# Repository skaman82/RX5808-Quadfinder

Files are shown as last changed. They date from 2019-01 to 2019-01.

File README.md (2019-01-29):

# RX5808-Quadfinder
Modified RX5808 Pro firmware for my Quadfinder project

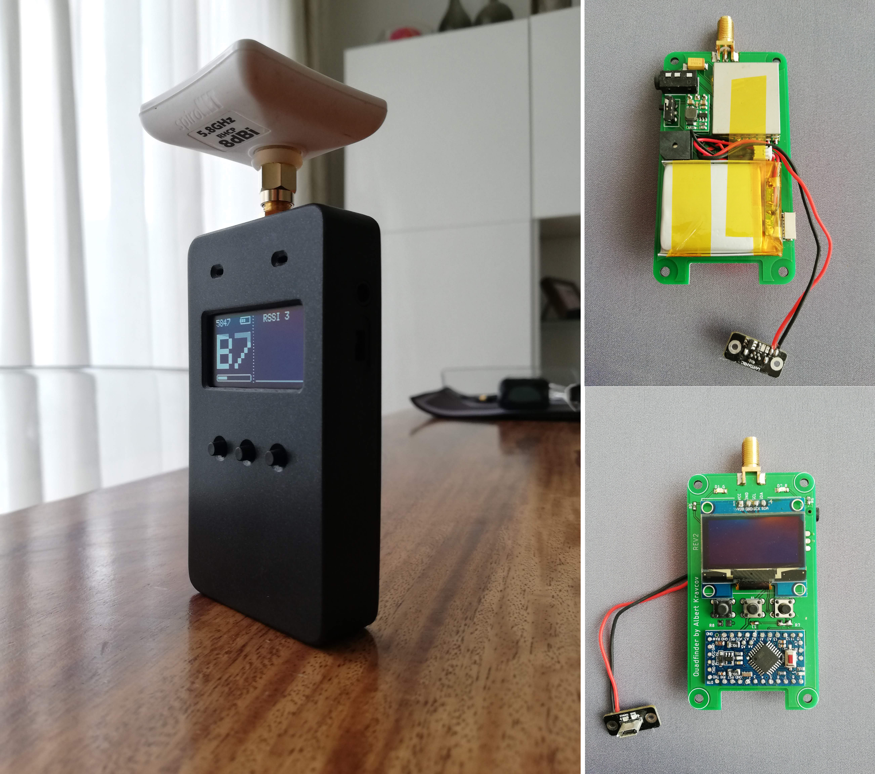
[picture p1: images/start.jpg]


Changes to the original Version: <br>
• UI overhaul<br>
• 1S voltage monitoring, low-voltage alarm, battery icon in the search UI<br>
• RSSI value in search mode<br>
• RSSI buzzer & LED beacon (configurable in search menu)<br><br>

# Different PCB power options<br>
1s lipo > 5V stepup U3V12F5<br>
2-3s lipo > 5V step-up/down S9V11F5 plus voltage divider R7(18k)+R8(4.7k) > !!!not yet usable, but soon!!!<br><br>

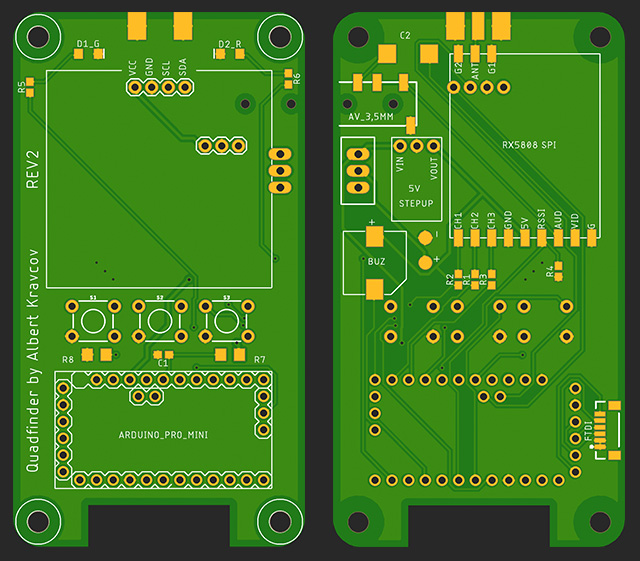
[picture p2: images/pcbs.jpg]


# Materials<br>
Arduino Mini<br>
1.3" OLED I2C Display<br>
3x 6x6x8mm tact buttons<br>
RX5808 SPI Module: <a href="https://de.aliexpress.com/item/1-ST-CK-RX5808-5-8G-SPI-Open-Source-Diversity-Empf-nger-FPV-AV-RX-modul/32852232709.html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">Link ></a><br>
5V stepup U3V12F5<br>
3.5mm AV socket: <a href="https://de.aliexpress.com/item/50pcs-PJ-320D-3-5mm-4Pin-Audio-Plug-jack-3-5-3-1-Headset-Headphone-Connector/32828520598.html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">Link ></a><br>
JST-SH 6pin socket<br> 
5v active buzzer SMD: <a href="https://de.aliexpress.com/item/3V-5V-ultra-small-SMD-active-patch-buzzer-9-5mm-9-5mm-5mm-square/1706981111.html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">Link ></a><br>
1s lipo: <a href="https://de.aliexpress.com/item/1-st-cke-3-7-v-500-mah-Lithium-Polymer-Batterie-3-7-v-Volt-503035/32950407438.html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">Link ></a><br>
2x 1206 LEDs (D1, D2)<br>
2x 330 0603 Resistor(R5, R6)<br>
3x 1k 0603 Resistor (R1, R2, R3)<br>
100k 0603 Resistor (R4)<br>
100nF 0603 cap (C1)<br>
10uF 1206 tantalum cap (c2) - optional, bridge otherwise.<br>
Mini slide switch: <a href="https://de.aliexpress.com/item/20-st-cke-MSS22D18-Mini-DIP-Schiebeschalter-1P2T-3Pin-f-r-DIY-Elektronische-Zubeh-r-Mikroschalter/32859694454.html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">Link ></a><br>
500mAh Lipo charger: <a href="https://www.banggood.com/Lantian-1S-3_7V-4_2V-0_4A-Android-Micro-USB-Lipo-Battery-Charger-Board-Module-for-FPV-RC-Drone-p-1347517.html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">Link ></a><br>
4x M3 brass inserts and 4x M3 screws<br>
11mm SMA PCB socket

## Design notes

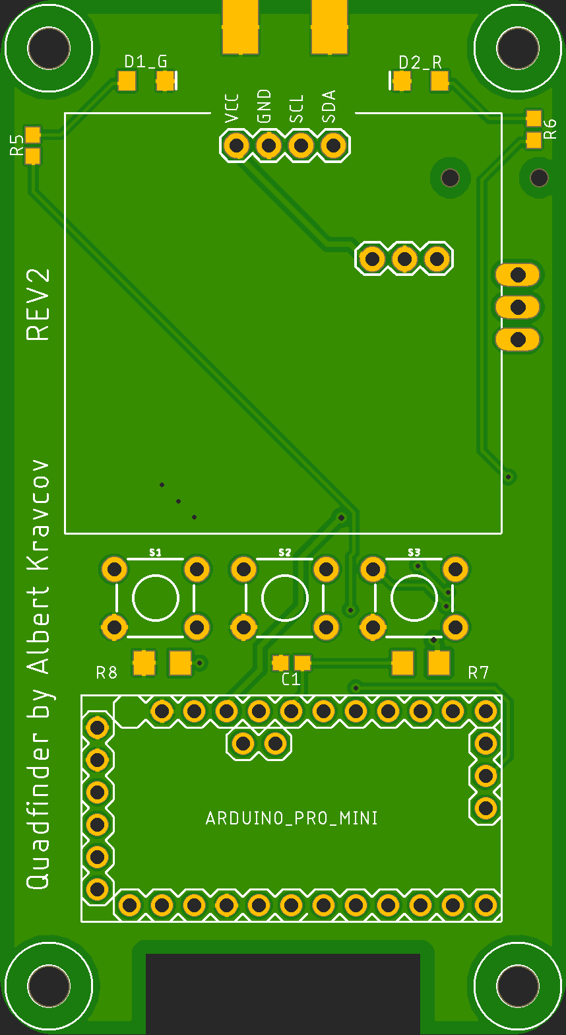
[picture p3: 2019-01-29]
PCB/Gerber/Quarfinder rev2_top.png

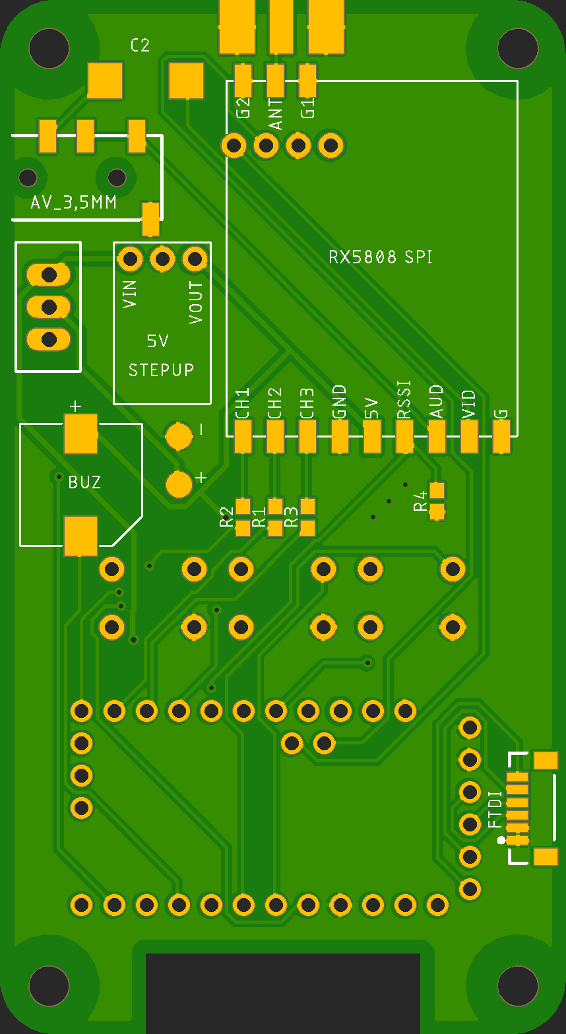
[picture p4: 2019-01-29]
Case/tex/Quarfinder rev2_bottom.png

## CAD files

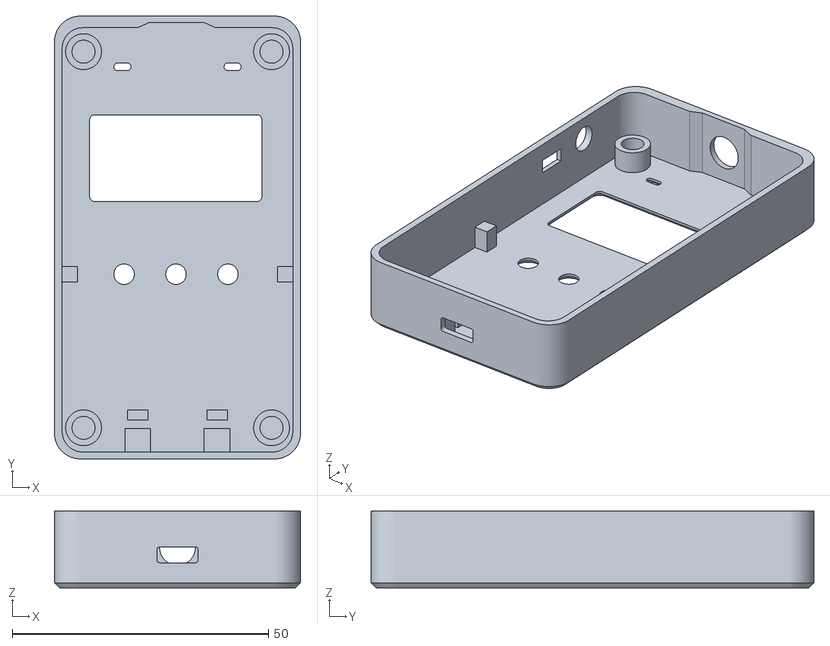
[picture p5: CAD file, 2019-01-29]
Case/Case_front.stl
48.0 x 86.4 x 15.0

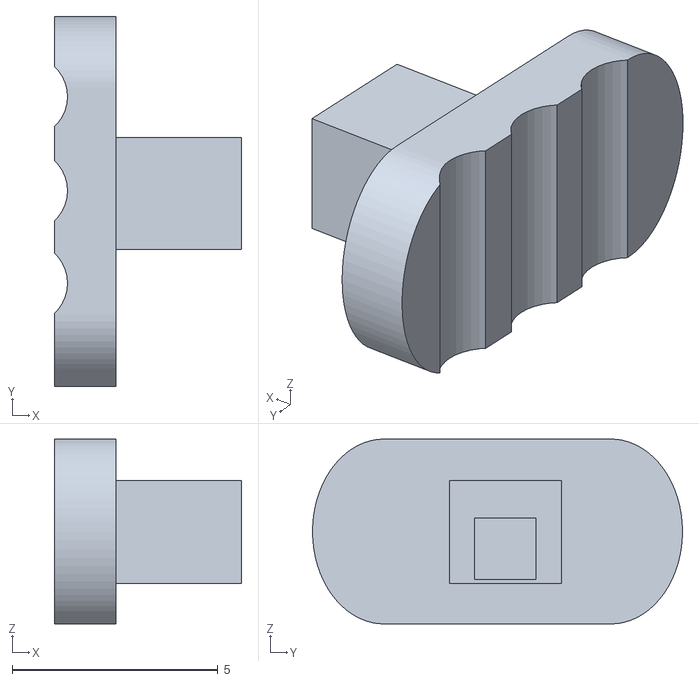
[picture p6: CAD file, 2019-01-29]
Case/Finals/Case_sw_fixed.stl
4.56 x 9.00 x 4.50

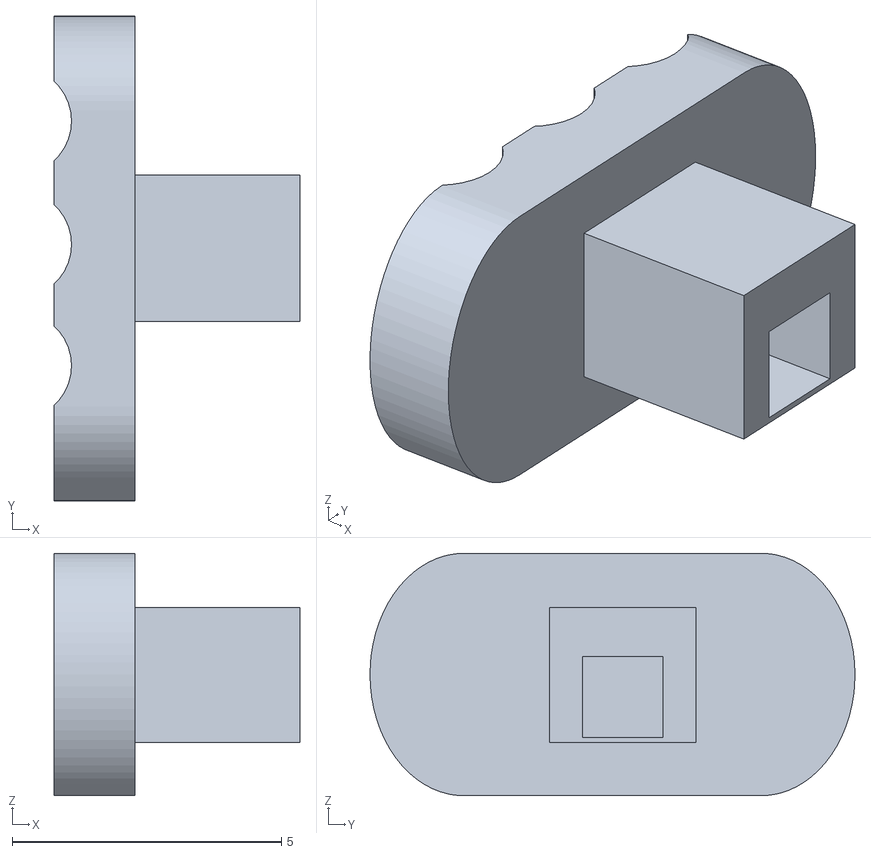
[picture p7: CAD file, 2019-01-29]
Case/Case_sw.stl
4.56 x 9.00 x 4.50

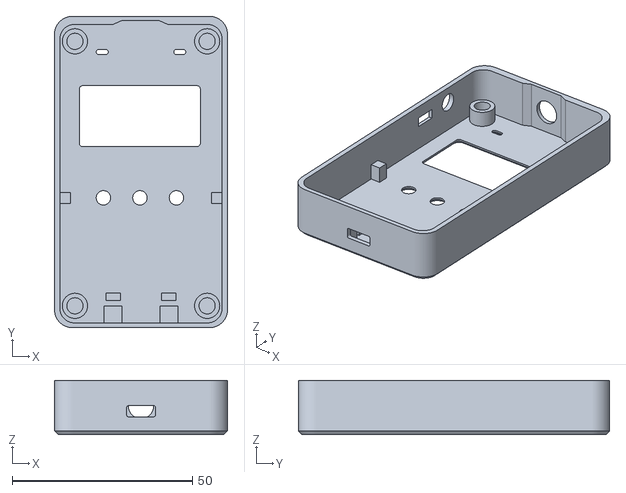
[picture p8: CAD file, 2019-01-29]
Case/Finals/Case_front_fixed.stl
48.0 x 86.4 x 15.0

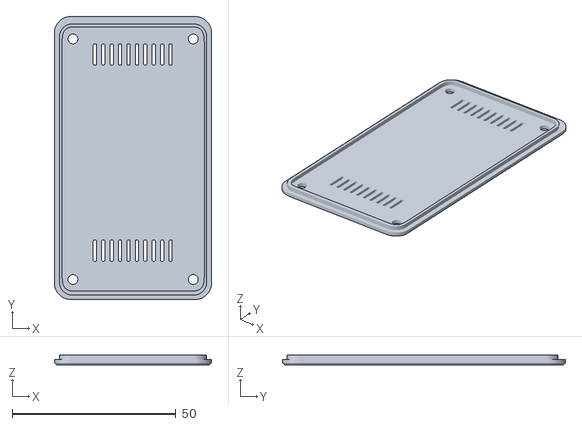
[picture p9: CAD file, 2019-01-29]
Case/Case_back.stl
48.0 x 86.4 x 2.93

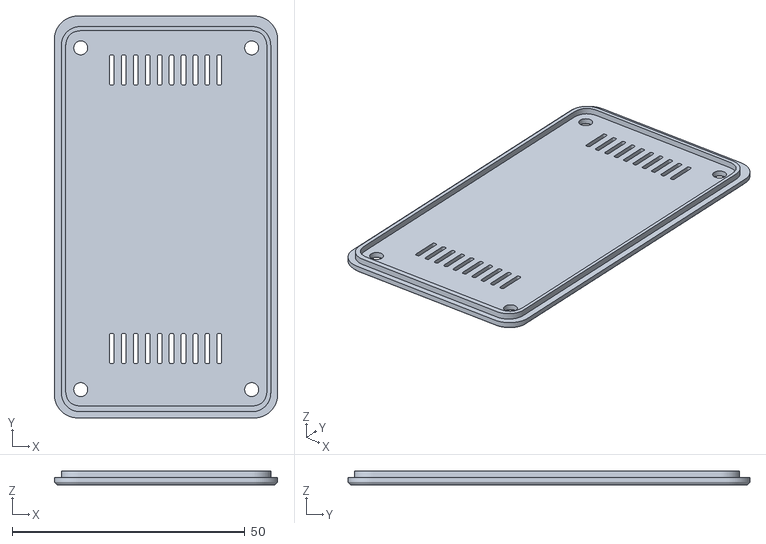
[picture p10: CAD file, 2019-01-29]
Case/Finals/Case_back_fixed.stl
48.0 x 86.4 x 2.93

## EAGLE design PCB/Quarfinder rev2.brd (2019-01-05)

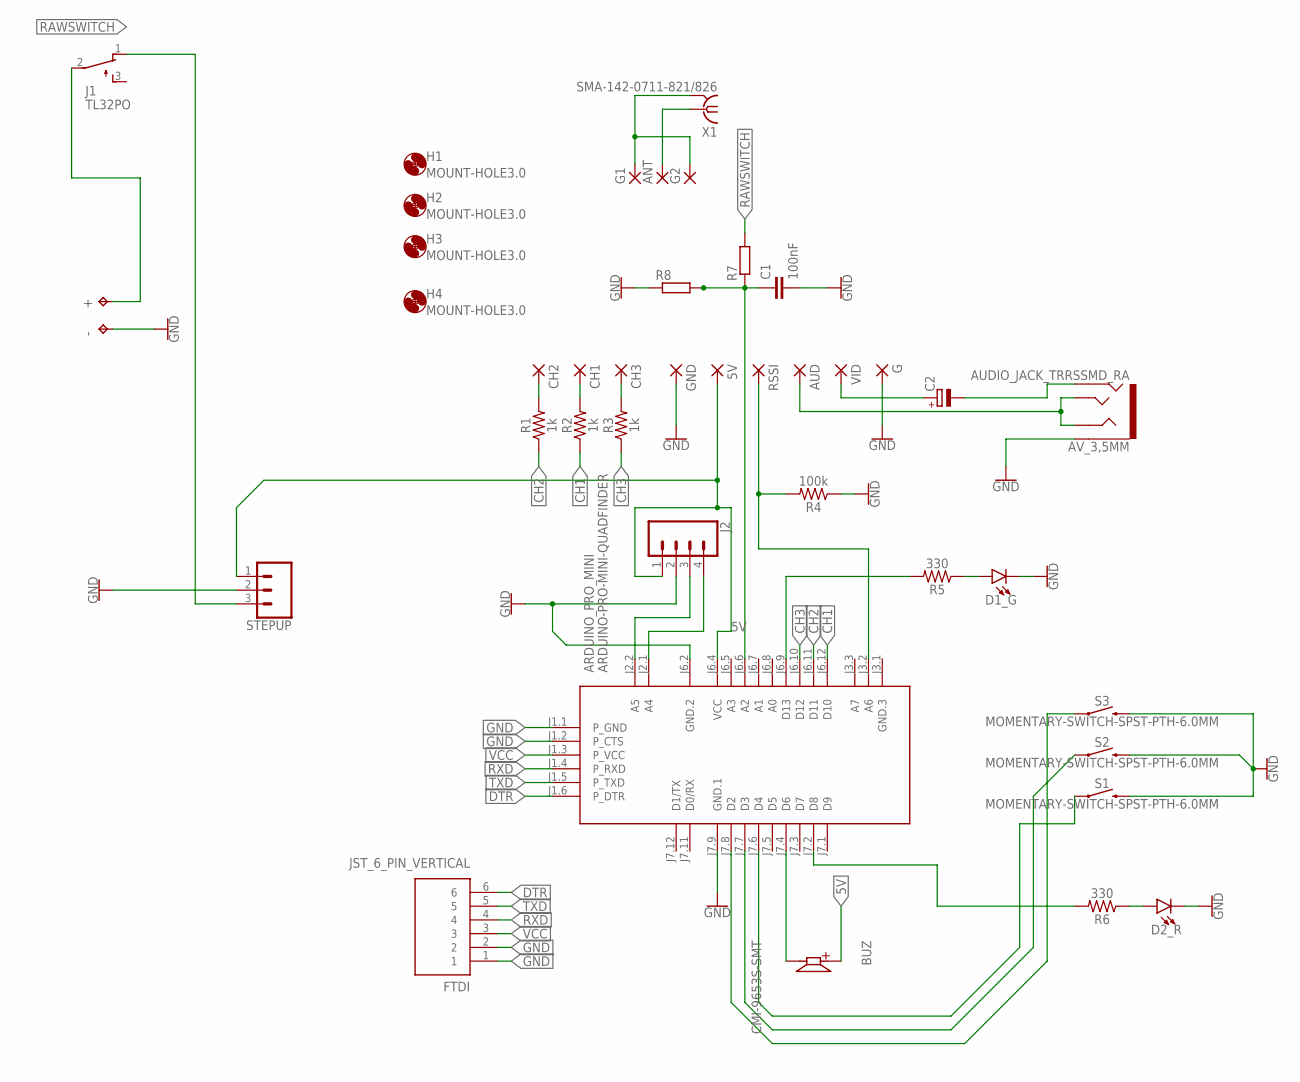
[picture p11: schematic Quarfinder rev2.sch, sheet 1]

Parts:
5V: SMD2; SMD1,27-2,54
+: TPTP20R; TP20R
-: TPTP20R; TP20R
ANT: SMD2; SMD1,27-2,54
ARDUINO_PRO_MINI: ARDUINO-PRO-MINI-QUADFINDER; ARDUINO-PRO-MINI
AUD: SMD2; SMD1,27-2,54
AV_3,5MM: AUDIO_JACK_TRRSSMD_RA; AUDIO_JACK_3.5MM_TRRS_SMD_RA
BUZ: CMI-9653S-SMT; CUI_CMI-9653S-SMT
C1: 100nF; 0603
C2: CPOL-EUD/7343-31R; D/7343-31R
CH1, CH2, CH3: SMD2; SMD1,27-2,54
D1_G, D2_R: LED1206; LED-1206
FTDI: JST_6_PIN_VERTICAL; JST-6-SMD-VERT-1.0MM
G, G1, G2: SMD2; SMD1,27-2,54
GND: SMD2; SMD1,27-2,54
H1, H2, H3, H4: MOUNT-HOLE3.0; 3,0
J1: TL32PO; TL3XPO
J2: CONN_04; 1X04
R1, R2, R3: 1k; 0603
R4: 100k; 0603
R5, R6: 330; 0603
R7, R8: R-EU_R1206; R1206
RSSI: SMD2; SMD1,27-2,54
S1, S2, S3: MOMENTARY-SWITCH-SPST-PTH-6.0MM; TACTILE_SWITCH_PTH_6.0MM
STEPUP: CONN_03; 1X03
VID: SMD2; SMD1,27-2,54
X1: SMA-142-0711-821/826; J502-ND-142-0711-821/826

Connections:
5V: 5V.1, ARDUINO_PRO_MINI.J6.4 (VCC), BUZ.P, J2.1, STEPUP.1
CH1: ARDUINO_PRO_MINI.J6.12 (D10), R2.1
CH2: ARDUINO_PRO_MINI.J6.11 (D11), R1.1
CH3: ARDUINO_PRO_MINI.J6.10 (D12), R3.1
DTR: ARDUINO_PRO_MINI.J1.6 (P_DTR), FTDI.6
GND: -.TP, ARDUINO_PRO_MINI.J1.1 (P_GND), ARDUINO_PRO_MINI.J1.2 (P_CTS), ARDUINO_PRO_MINI.J6.2 (GND.2), ARDUINO_PRO_MINI.J7.9 (GND.1), AV_3,5MM.EARTH, C1.2, D1_G.C, D2_R.C, FTDI.1, FTDI.2, G.1, G1.1, G2.1, GND.1, J2.2, R4.1, R8.1, S1.3 (2), S2.3 (2), S3.3 (2), STEPUP.2, X1.G@1 (2), X1.G@2 (2), X1.G@3 (2), X1.G@4 (2)
unnamed: ANT.1, X1.1
unnamed: C2.+, VID.1
unnamed: CH2.1, R1.2
unnamed: CH1.1, R2.2
unnamed: CH3.1, R3.2
unnamed: ARDUINO_PRO_MINI.J2.1 (A4), J2.4
unnamed: ARDUINO_PRO_MINI.J2.2 (A5), J2.3
unnamed: ARDUINO_PRO_MINI.J3.2 (A6), R4.2, RSSI.1
unnamed: ARDUINO_PRO_MINI.J7.8 (D2), S3.1
unnamed: ARDUINO_PRO_MINI.J7.4 (D6), BUZ.N
unnamed: ARDUINO_PRO_MINI.J7.7 (D3), S2.1
unnamed: ARDUINO_PRO_MINI.J7.6 (D4), S1.1
unnamed: D1_G.A, R5.1
unnamed: ARDUINO_PRO_MINI.J6.9 (D13), R5.2
unnamed: D2_R.A, R6.1
unnamed: AUD.1, AV_3,5MM.RING1, AV_3,5MM.TIP
unnamed: ARDUINO_PRO_MINI.J7.2 (D8), R6.2
unnamed: AV_3,5MM.RING2, C2.-
unnamed: ARDUINO_PRO_MINI.J6.6 (A2), C1.1, R7.1, R8.2
RAWSWITCH: J1.1 (O), R7.2, STEPUP.3
RXD: ARDUINO_PRO_MINI.J1.4 (P_RXD), FTDI.4
TXD: ARDUINO_PRO_MINI.J1.5 (P_TXD), FTDI.5
VCC: ARDUINO_PRO_MINI.J1.3 (P_VCC), FTDI.3
VIN: +.TP, J1.2

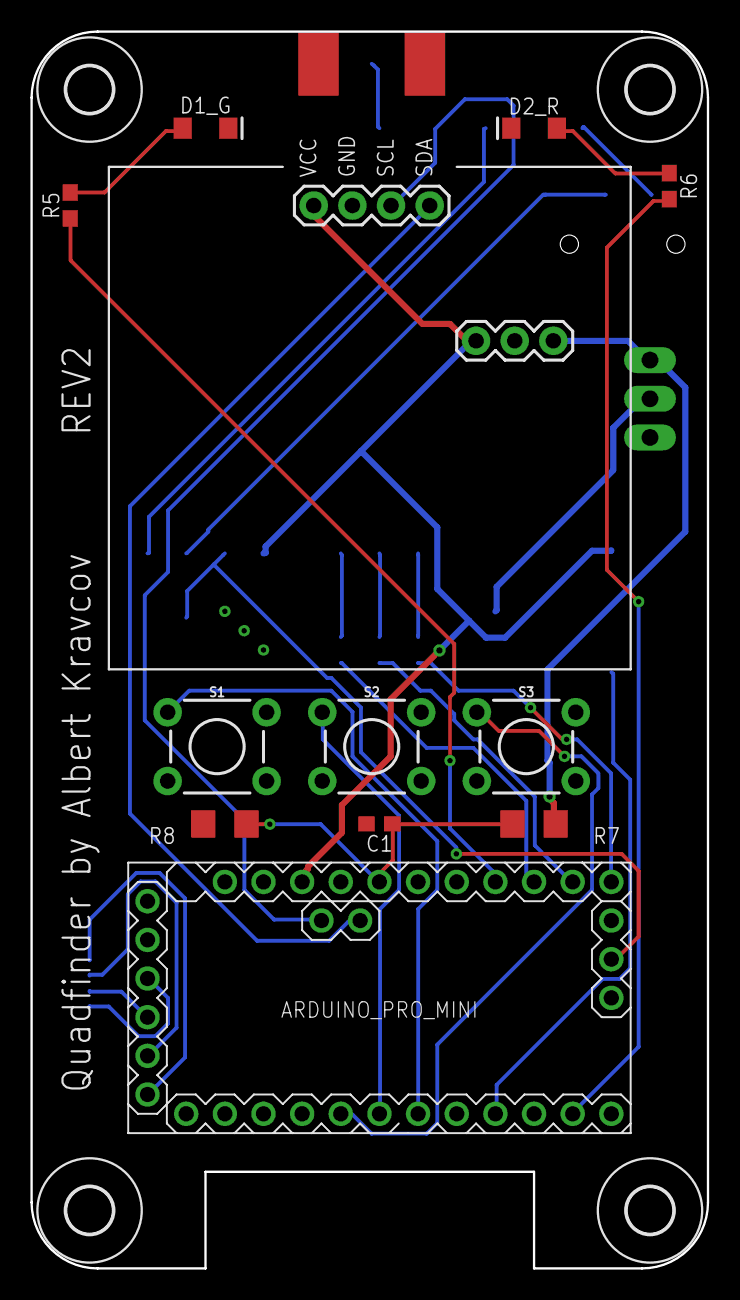
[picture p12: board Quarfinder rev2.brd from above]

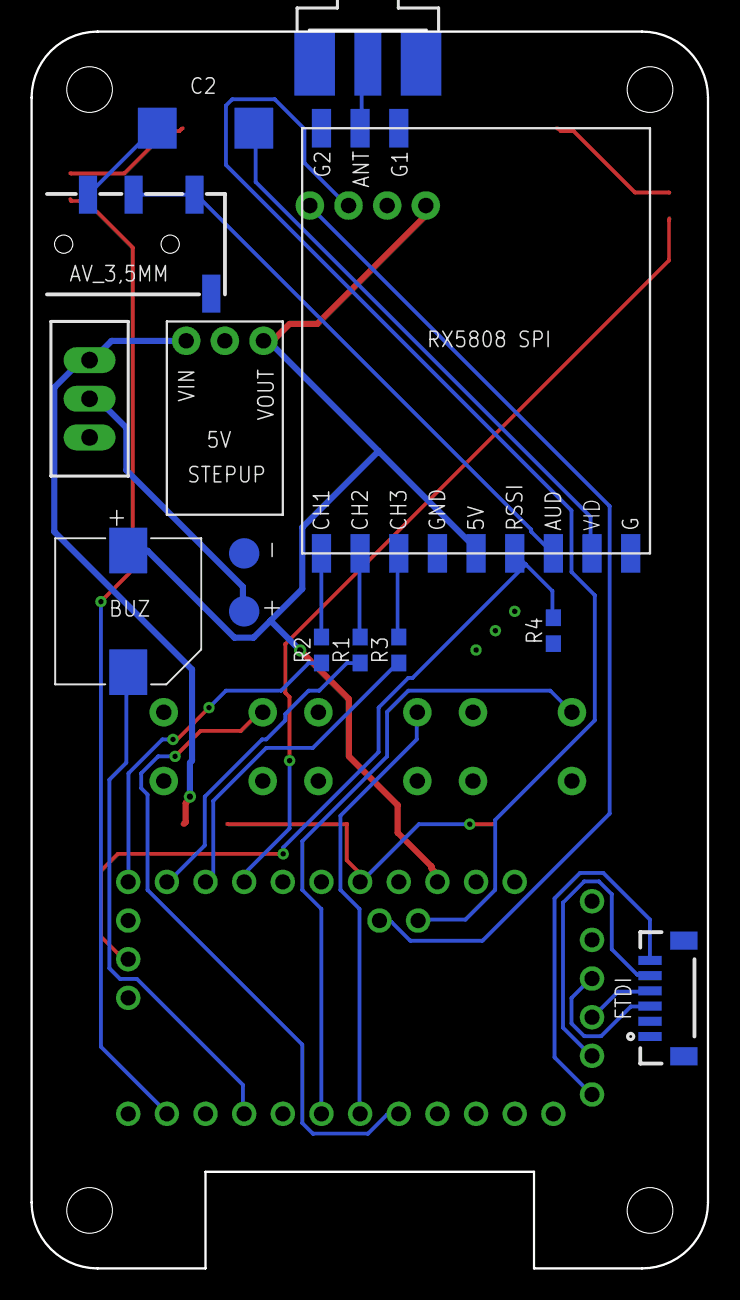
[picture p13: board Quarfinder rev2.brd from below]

Board: 2 copper layers, 44.4 x 81.3 mm, 41 parts (24 on the bottom side), 30 nets.

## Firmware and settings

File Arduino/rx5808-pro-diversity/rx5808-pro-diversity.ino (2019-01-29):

/*
 * SPI driver based on fs_skyrf_58g-main.c Written by Simon Chambers
 * TVOUT by Myles Metzel
 * Scanner by Johan Hermen
 * Inital 2 Button version by Peter (pete1990)
 * Refactored and GUI reworked by Marko Hoepken
 * Universal version my Marko Hoepken
 * Diversity Receiver Mode and GUI improvements by Shea Ivey
 * OLED Version by Shea Ivey
 * Seperating display concerns by Shea Ivey

The MIT License (MIT)

Copyright (c) 2015 Marko Hoepken

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
THE SOFTWARE IS PROVIDED "AS IS", WITHOUT WARRANTY OF ANY KIND, EXPRESS OR
IMPLIED, INCLUDING BUT NOT LIMITED TO THE WARRANTIES OF MERCHANTABILITY,
FITNESS FOR A PARTICULAR PURPOSE AND NONINFRINGEMENT. IN NO EVENT SHALL THE
AUTHORS OR COPYRIGHT HOLDERS BE LIABLE FOR ANY CLAIM, DAMAGES OR OTHER
LIABILITY, WHETHER IN AN ACTION OF CONTRACT, TORT OR OTHERWISE, ARISING FROM,
OUT OF OR IN CONNECTION WITH THE SOFTWARE OR THE USE OR OTHER DEALINGS IN THE
SOFTWARE.
*/


#include "settings.h"
#include "settings_internal.h"
#include "settings_eeprom.h"

#include "channels.h"
#include "receiver.h"
#include "receiver_spi.h"
#include "buttons.h"
#include "state.h"

#include "ui.h"

float voltage;

static void globalMenuButtonHandler(
    Button button,
    Buttons::PressType pressType
);


void setup()
{
    setupPins();

    // Enable buzzer and LED for duration of setup process.
    digitalWrite(PIN_LED, HIGH);
    digitalWrite(8, HIGH);
    digitalWrite(PIN_BUZZER, LOW);
   

    setupSettings();

    StateMachine::setup();
    Receiver::setup();
    Ui::setup();

    Receiver::setActiveReceiver(Receiver::ReceiverId::A);

    #ifdef USE_IR_EMITTER
        Serial.begin(9600);
    #endif
    #ifdef USE_SERIAL_OUT
        Serial.begin(250000);
    #endif
    
    Serial.begin(9600);
    
    // Setup complete.
    digitalWrite(PIN_LED, LOW);
    digitalWrite(8, LOW);
    digitalWrite(PIN_BUZZER, HIGH);

    Buttons::registerChangeFunc(globalMenuButtonHandler);

    // Switch to initial state.
    StateMachine::switchState(StateMachine::State::SEARCH);
}

void setupPins() {
    pinMode(PIN_LED, OUTPUT);
    pinMode(8, OUTPUT);
    pinMode(PIN_BUZZER, OUTPUT);
    pinMode(PIN_BUTTON_UP, INPUT_PULLUP);
    pinMode(PIN_BUTTON_MODE, INPUT_PULLUP);
    pinMode(PIN_BUTTON_DOWN, INPUT_PULLUP);
    pinMode(PIN_BUTTON_SAVE, INPUT_PULLUP);

    pinMode(PIN_LED_A,OUTPUT);
    #ifdef USE_DIVERSITY
        pinMode(PIN_LED_B,OUTPUT);
    #endif

    pinMode(PIN_RSSI_A, INPUT_PULLUP);
    #ifdef USE_DIVERSITY
        pinMode(PIN_RSSI_B, INPUT_PULLUP);
    #endif

    pinMode(PIN_SPI_SLAVE_SELECT, OUTPUT);
    pinMode(PIN_SPI_DATA, OUTPUT);
	pinMode(PIN_SPI_CLOCK, OUTPUT);

    digitalWrite(PIN_SPI_SLAVE_SELECT, HIGH);
    digitalWrite(PIN_SPI_CLOCK, LOW);
    digitalWrite(PIN_SPI_DATA, LOW);
}

void setupSettings() {
    EepromSettings.load();
    Receiver::setChannel(EepromSettings.startChannel);
}


void loop() {
    
   

   
   
    Receiver::update();
    Buttons::update();
    StateMachine::update();
    Ui::update();
    EepromSettings.update();

    if (
        StateMachine::currentState != StateMachine::State::SCREENSAVER
        && StateMachine::currentState != StateMachine::State::BANDSCAN
        && (millis() - Buttons::lastChangeTime) >
            (SCREENSAVER_TIMEOUT * 1000)
    ) {
        // StateMachine::switchState(StateMachine::State::SCREENSAVER); // deactivate screensaver
    }
}


static void globalMenuButtonHandler(
    Button button,
    Buttons::PressType pressType
) {
    if (
        StateMachine::currentState != StateMachine::State::MENU &&
        button == Button::MODE &&
        pressType == Buttons::PressType::HOLDING
    ) {
        StateMachine::switchState(StateMachine::State::MENU);
    }
}

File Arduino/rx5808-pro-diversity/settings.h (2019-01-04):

/*
 * Setings file by Shea Ivey

The MIT License (MIT)

Copyright (c) 2015 Shea Ivey

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
THE SOFTWARE IS PROVIDED "AS IS", WITHOUT WARRANTY OF ANY KIND, EXPRESS OR
IMPLIED, INCLUDING BUT NOT LIMITED TO THE WARRANTIES OF MERCHANTABILITY,
FITNESS FOR A PARTICULAR PURPOSE AND NONINFRINGEMENT. IN NO EVENT SHALL THE
AUTHORS OR COPYRIGHT HOLDERS BE LIABLE FOR ANY CLAIM, DAMAGES OR OTHER
LIABILITY, WHETHER IN AN ACTION OF CONTRACT, TORT OR OTHERWISE, ARISING FROM,
OUT OF OR IN CONNECTION WITH THE SOFTWARE OR THE USE OR OTHER DEALINGS IN THE
SOFTWARE.
*/

#ifndef SETTINGS_H
#define SETTINGS_H


// === Display Module ==========================================================
//
// You can choose one display module only. Only 128x64 OLED displays are
// supported.
//
// =============================================================================

// SSH1106 needs https://github.com/badzz/Adafruit_SH1106 installed.
#include <Adafruit_SH1106.h>

#define SH1106

//#define TVOUT_SCREENS
#define OLED_128x64_ADAFRUIT_SCREENS

// Enable this if your screen is upside down.
//#define USE_FLIP_SCREEN

#ifdef OLED_128x64_ADAFRUIT_SCREENS
    #define OLED_ADDRESS 0x3C // I2C address for display (0x3C or 0x3D, usually)
#endif

// === Receiver Module =========================================================
//
// Select which receiever you are using. Required for time tuning.
//
// =============================================================================

#define RX5808
//#define RX5880

// Can enable this to powerdown the audio blocks on the RX58xx if you don't
// need it. Save a tiny bit of power, make your videos less noisy.
//
// WARNING: Makes RSSI act a little weird.
//#define DISABLE_AUDIO

// === Features ===============================================================
//
// Keep in mind that there is limited program memory. Only enable the features
// you need.
//
// =============================================================================

//#define USE_DIVERSITY

// Enable this to switch receivers much faster. This uses the port registers
// to switch rather than the Arduino helper functions.
//
// WARNING: You can only use this if your receivers are on the same port.
// Arduino/ATmega has 3 ports: PORTD, PORTB, and PORTC. The "default" hardware
// configuration uses pins A0 and A1 (PORTC), so if you're using reasonably
// standard hardware then this should be fine.
//
// PORTC: Pins A0-A7
// PORTD: 0-7
// PORTB: 8-13
//#define USE_DIVERSITY_FAST_SWITCHING

//#define USE_IR_EMITTER
//#define USE_SERIAL_OUT // Not compatible with IR emitter.

// You can use any of the arduino analog pins to measure the voltage of the
// battery. See additional configuration below.
#define USE_VOLTAGE_MONITORING

// Choose if you wish to use 8 additional channels:
//     5362 MHz
//     5399 MHz
//     5436 MHz
//     5473 MHz
//     5510 MHz
//     5547 MHz
//     5584 MHz
//     5621 MHz
// Local laws may prohibit the use of these frequencies so use at your own risk!
#define USE_LBAND

// === Pins ====================================================================

// Buttons (required)
#define PIN_BUTTON_UP 2
#define PIN_BUTTON_MODE 3

// Buttons (optional, for comfort)
#define PIN_BUTTON_DOWN 4
#define PIN_BUTTON_SAVE 5

#define PIN_LED 13
#define PIN_BUZZER 6 // Must be an active buzzer, not passive.

#define PIN_SPI_DATA 10
#define PIN_SPI_SLAVE_SELECT 11
#define PIN_SPI_CLOCK 12

#define PIN_RSSI_A A6
#define PIN_LED_A A0
#ifdef USE_DIVERSITY
    #define PIN_LED_B A1
    #define PIN_RSSI_B A7
#endif

#ifdef USE_VOLTAGE_MONITORING
    #ifdef TVOUT_SCREENS
        #define PIN_VBAT A4
    #else
        #define PIN_VBAT A2
    #endif
#endif

// === Diversity ===============================================================

#ifdef USE_DIVERSITY
    // RSSI strength should be greater than the value below (percent) over the
    // other receiver before we switch. This pervents flicker when RSSI values
    // are close and delays diversity checks counter.
    #define DIVERSITY_HYSTERESIS 2

    // How long (ms) the RSSI strength has to have a greater difference than the
    // above before switching.
    #define DIVERSITY_HYSTERESIS_PERIOD 5
#endif

// === Voltage Monitoring ======================================================
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

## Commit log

2019-01-04 upload current work state
    [Quarfinder rev2.brd, Quarfinder rev2.sch, Quarfinder rj45.brd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]
2019-01-04 UI: better low voltage warning
2019-01-04 battery animation
2019-01-05 fixed side effects between auto search and beacon
    [state_search_ui.cpp]
2019-01-05 final pcb
    [Quarfinder rev2.brd]
2019-01-21 Initial Case work
2019-01-22 Case v1
    [Case_front.stl, Case_front_fixed.stl]
2019-01-23 Some more work on the case
    [Case_back.stl, Case_back_fixed.stl, Case_front.stl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]
2019-01-29 LED and Buzzer bugfix
    [rx5808-pro-diversity.ino, state_search_ui.cpp]
2019-01-29 Final case
    [Case_front.stl, Case_front_fixed.stl, Case_sw.stl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]

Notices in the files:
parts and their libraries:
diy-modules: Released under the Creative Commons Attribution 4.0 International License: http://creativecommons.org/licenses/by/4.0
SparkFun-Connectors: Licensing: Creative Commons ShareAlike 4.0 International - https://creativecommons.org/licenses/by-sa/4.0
